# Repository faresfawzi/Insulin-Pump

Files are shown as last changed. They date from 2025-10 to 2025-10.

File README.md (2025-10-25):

# Open Source AI-Enhanced 3D-Printed Insulin Pump
## Abstract
This research aims to develop functional 3D printed low-cost wearable insulin pumps for precise and personalized dosing for type 1 diabetes mellitus (T1DM) patients. The system utilizes artificial intelligence (AI) insulin to predict personalized bolus insulin dosages and send the dosing configuration wirelessly to an in-house developed IoT-reconfigurable pumping system to deliver the specified dosage to the patient. Historical patients’ data are fed to a cloud-based machine learning model to predict the personalized amount of bolus insulin based on the patient’s blood glucose levels, the amount of carbohydrates consumed, and physical activity. The system delivers U100 insulin bolus dosage at a flow rate of 750μl/min against an estimated 0.764 kPa backpressure produced by the patient’s subcutaneous tissue, which is 6 to 8 times faster than current insulin pumping systems. In addition to the system’s AI-enhancement, IoT connectivity, small footprint, and low power consumption, the system’s cost is predicted at under $35, making it an excellent candidate to fill a market gap and act as a fully autonomous artificial pancreas that improves the quality of life of T1DM patients.

## Citation

If you build on this project, please cite this paper.

```
@inproceedings{fawzi2023open,
  title={Open Source AI-Enhanced 3D-Printed Insulin Pump},
  author={Fawzi, Fares and Sedky, Mostafa and Abohammar, Youssef and Sharara, Hossam and Serry, Mohamed},
  booktitle={2023 IEEE Applied Sensing Conference (APSCON)},
  pages={1--4},
  year={2023},
  organization={IEEE}
}
```

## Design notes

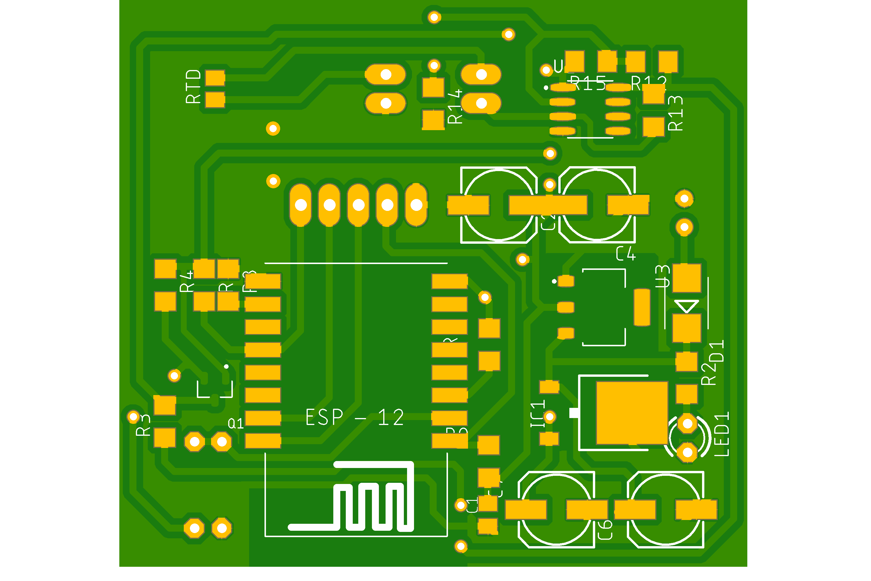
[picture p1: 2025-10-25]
RTD/RTD Sesnor.png

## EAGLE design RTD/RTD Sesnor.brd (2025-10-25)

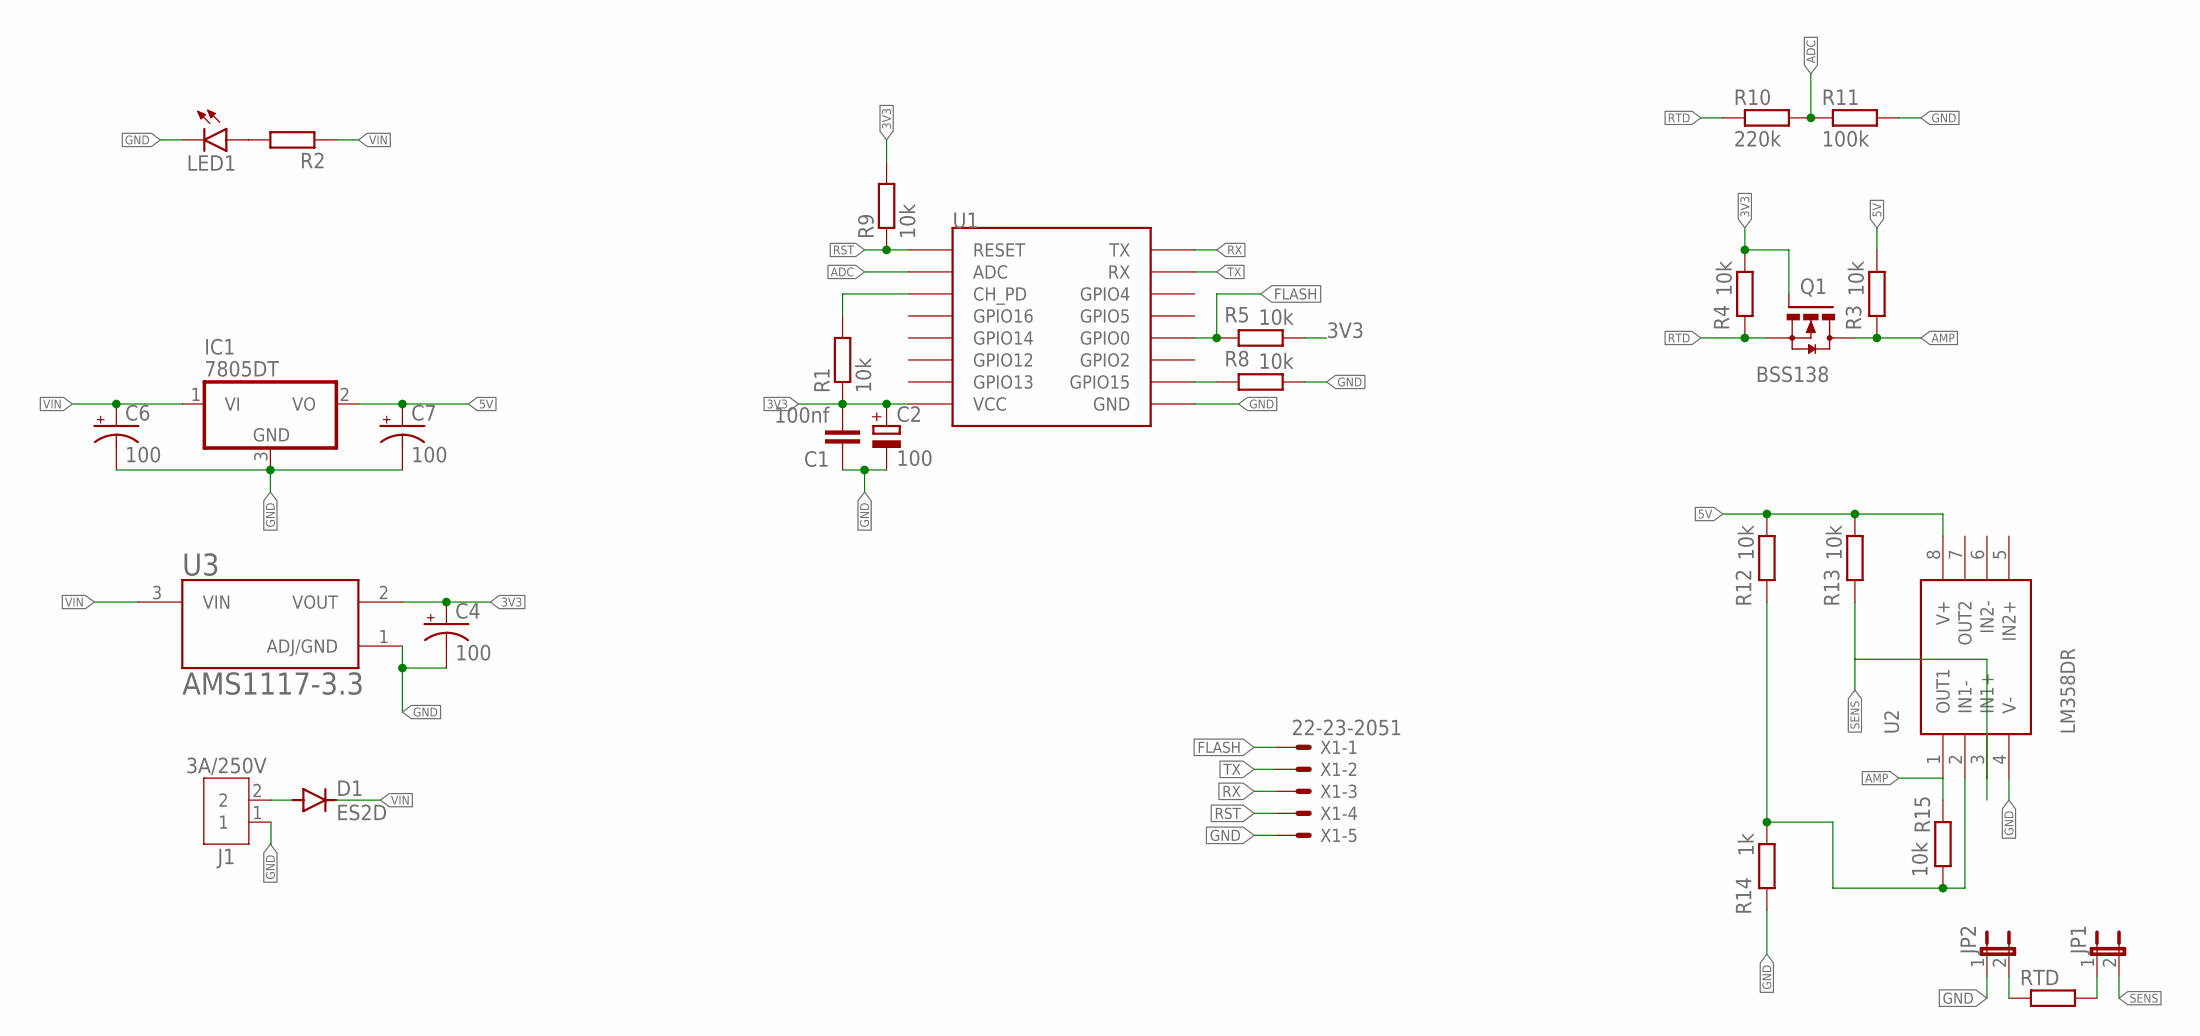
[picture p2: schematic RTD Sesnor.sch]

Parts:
C1: 100nf; C0805K
C2, C4, C6, C7: 100; 153CLV-0605
D1: ES2D; SMB
IC1: 7805DT; TO252
J1: 3A/250V; B2B-XH-A
JP1, JP2: JP1E; JP1
LED1: LED3MM
Q1: BSS138; SOT23-3
R1, R3, R4, R5, R8, R9, R12, R13, R15: 10k; R1206
R2: R-EU_R1206; R1206
R10: 220k; 0204/7
R11: 100k; 0204/7
R14: 1k; R1206
RTD: R-EU_M0805; M0805
U1: ESP12SMD; ESP12-SMD
U2: LM358DR
U3: AMS1117-3.3; SOT229P700X180-4N
X1: 22-23-2051

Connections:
3V3: C1.2, C2.+, C4.+, Q1.1 (G), R1.1, R4.1, R5.1, R9.2, U1.VCC, U3.2 (VOUT)
5V: C7.+, IC1.2 (VO), R3.1, R12.1, R13.1, U2.8 (V+)
ADC: R10.2, R11.1, U1.ADC
AMP: Q1.3 (D), R3.2, R15.2, U2.1 (OUT1)
FLASH: R5.2, U1.GPIO0, X1.1
GND: C1.1, C2.-, C4.-, C6.-, C7.-, IC1.3 (GND), J1.1, JP2.1, LED1.K (C), R8.1, R11.2, R14.2, U1.GND, U2.4 (V-), U3.1 (ADJ/GND), X1.5
unnamed: R1.2, U1.CH_PD
unnamed: LED1.A, R2.2
unnamed: JP2.2, RTD.1
unnamed: JP1.1, RTD.2
unnamed: R8.2, U1.GPIO15
unnamed: D1.A, J1.2
unnamed: R12.2, R14.1, R15.1, U2.2 (IN1-)
RST: R9.1, U1.RESET, X1.4
RTD: Q1.2 (S), R4.2, R10.1
RX: U1.TXD0 (TX), X1.3
SENS: JP1.2, R13.2, U2.3 (IN1+)
TX: U1.RXD0 (RX), X1.2
VIN: C6.+, D1.C, IC1.1 (VI), R2.1, U3.3 (VIN)

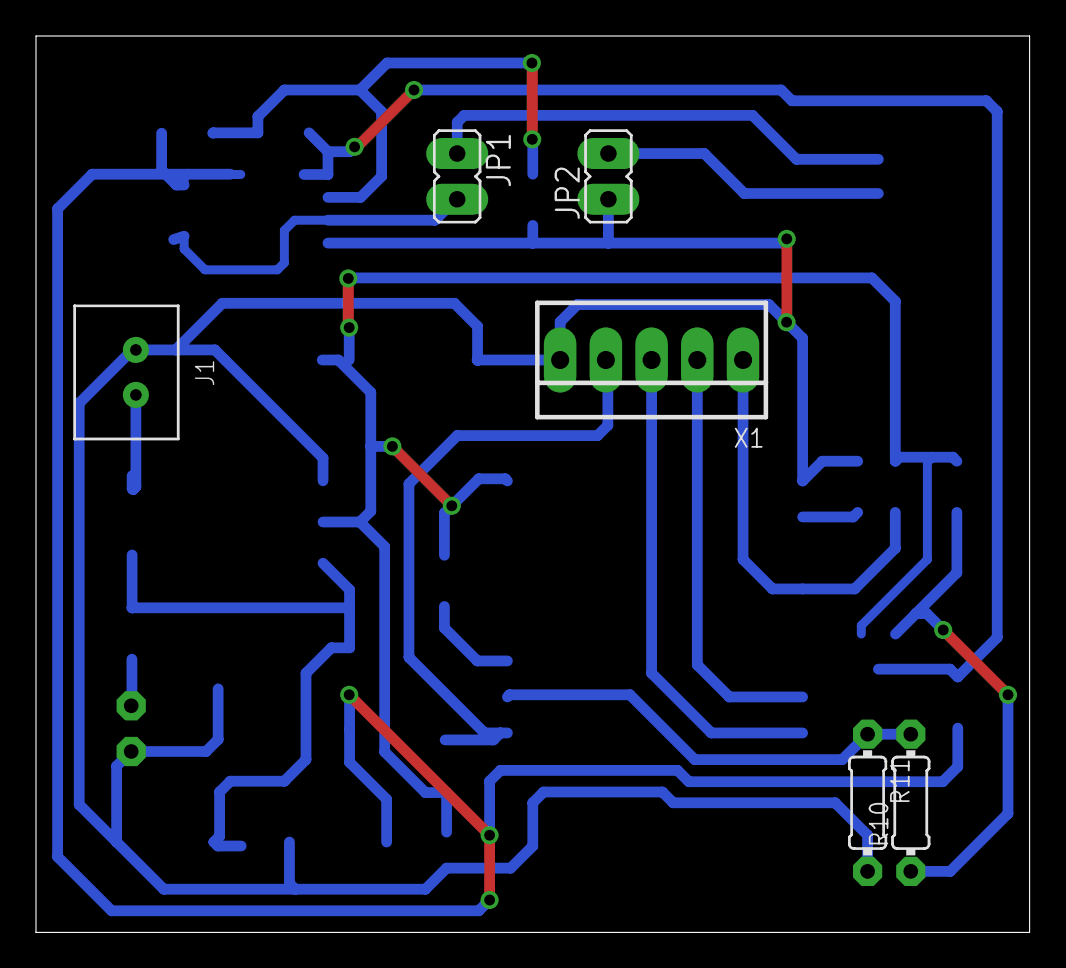
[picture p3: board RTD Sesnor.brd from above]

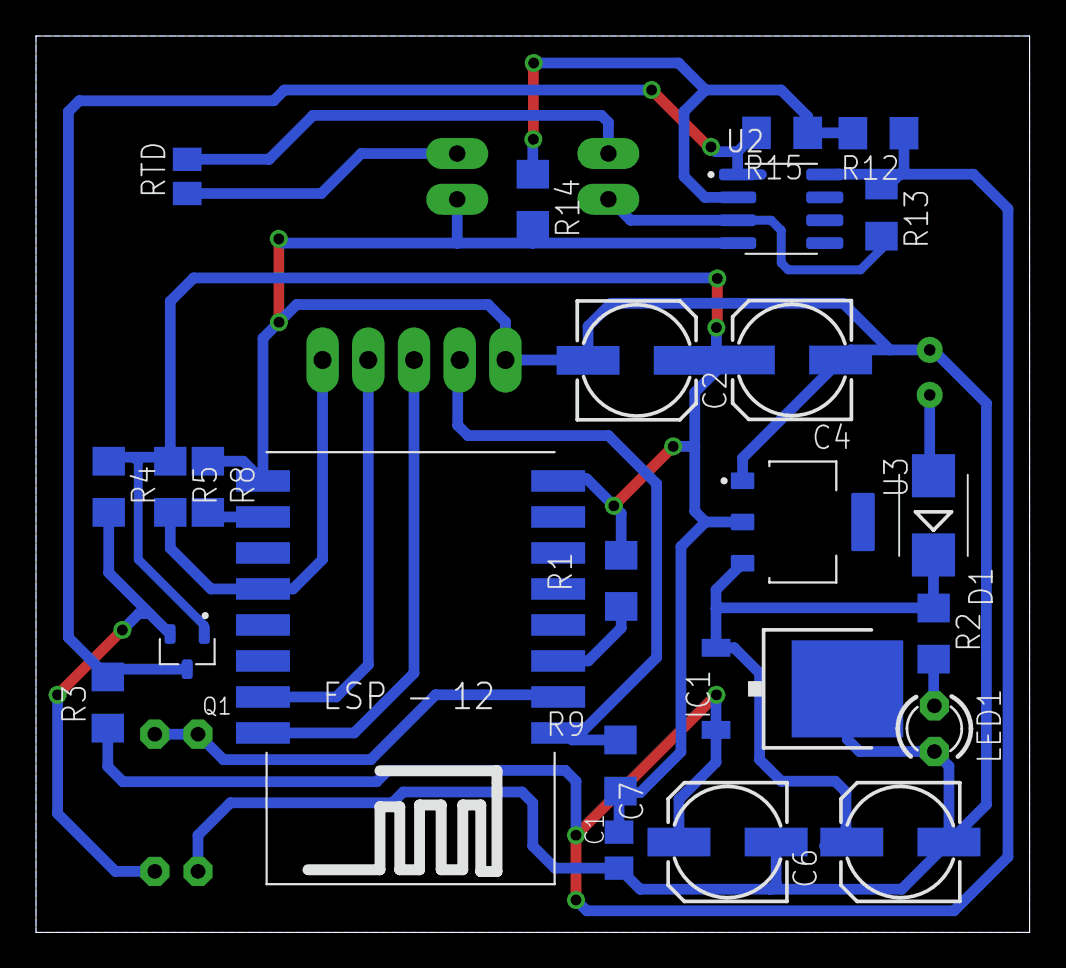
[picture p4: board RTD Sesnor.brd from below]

Board: 2 copper layers, 55.2 x 49.8 mm, 30 parts (24 on the bottom side), 19 nets.

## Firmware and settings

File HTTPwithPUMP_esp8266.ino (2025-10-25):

float Sens=100; //mV/mT, this is 12.5 for A4 version
float Stc=0.0012; //%/Celcius
float Ta=25;
float Vq=5/2; //half of sensor input voltage
//float B1;
float B2;
float Distime[] = {};
float Vout1;
float Vout2;
//int HallPin1=A0;
//int HallPin2=A2; 
float Bact;

//******************CHANGE THIS**************************
float frequency=10;//Hz
const float flowrate=6.558222222; // ml/min 
//*****************************************************

const float dutyCycle=0.4;
float offTime=1000.0/frequency*(1-dutyCycle);
float onTime=1000.0/frequency*dutyCycle;

//float offTime=33;
//float onTime=12.5;

float power;
float time_on;
float time_off;
float total_time;
int  Writestatus = 200;
#define HallPin A4

#include <ESP8266WiFi.h>
#include <ESP8266HTTPClient.h>
#include <WiFiClient.h>

//#include <WiFi.h>
//#include <HTTPClient.h>
//#include <HttpClient.h>

#include <ArduinoJson.h>
const char* ssid = "Fares1";
const char* password = "mariam98";

//#define STASSID "Fares1"
//#define STAPSK  "mariam98"

//Your Domain name with URL path or IP address with path
String serverName = "https://t1ly8glf7c.execute-api.us-east-1.amazonaws.com/prod-get/data"; //aws API Gateway url, Need htps:// pre-fix for ESP32 sketch
const char* API_KEY = "uzpjEVoFFz3TZQkzGS8GxRHjHAYGxN181OwDplr4"; //Your AWS API-Key

// the following variables are unsigned longs because the time, measured in
// milliseconds, will quickly become a bigger number than can be stored in an int.
unsigned long lastTime = 0;
// Timer set to 10 minutes (600000)
//unsigned long timerDelay = 600000;
// Set timer to 5 seconds (5000)
unsigned long timerDelay = 5000;
unsigned long Uptime;
String json_post(float carbs);
double carbs_get=0;
double carbs_old=1000;
void setup() {
  Serial.begin(115200); 

  WiFi.begin(ssid, password);
  //WiFi.begin(STASSID, STAPSK);
  Serial.println("Connecting");
  while(WiFi.status() != WL_CONNECTED) {
    delay(500);
    Serial.print(".");
  }
  Serial.println("");
  Serial.print("Connected to WiFi network with IP Address: ");
  Serial.println(WiFi.localIP());
 
  Serial.println("Timer set to 5 seconds (timerDelay variable), it will take 5 seconds before publishing the first reading.");

  pinMode(19,OUTPUT);
  pinMode(21,OUTPUT);
  pinMode(18,OUTPUT);
  pinMode(2,OUTPUT);
  pinMode(4,OUTPUT);
  digitalWrite(19,LOW);   
  digitalWrite(21,LOW);
  digitalWrite(2,LOW);
  digitalWrite(4,LOW); 

   
  
}
String body;
bool flag=true;
void loop() {

  
  //Send an HTTP POST request every 10 minutes
  if ((millis() - lastTime) > timerDelay) {
    //Check WiFi connection status
    if(WiFi.status()== WL_CONNECTED){
     // Pump();
     carbs_get=json_get();
     while (carbs_get!= carbs_old){
     while (flag==true){
          
          Serial.println(carbs_get);
          carbs_old=carbs_get;

          String pred=json_post(carbs_get);

          Serial.println("Pred: ");
          Serial.println(pred);
          float pred_float=pred.toFloat();
      
          
      
  
      long   starttime = millis();
      long    endtime = starttime;
          while ((endtime - starttime) <=(((pred_float/100)*60/flowrate)*1000)) // do this loop for up to 1000mS
         // while ( (endtime - starttime) <= (((10.0/100)*60/flowrate)*1000)+2000) // do this loop for up to 1000mS
            {
                Serial.println("Pumping");       
                Pump();
                endtime = millis();
                Serial.println(endtime - starttime);
            }
          flag=false;

         

         }

      }

    }



    
}
}

double json_get(){
double carbs;
   // WiFiClient client;
    WiFiClientSecure client;
    client.setInsecure();
    HTTPClient http;
       //HTTPClient http;
      // Your Domain name with URL path or IP address with path
      String serverPath = "https://t1ly8glf7c.execute-api.us-east-1.amazonaws.com/prod-get/data";
      http.begin(client, serverPath.c_str());
      
      // Send HTTP GET request
      int httpResponseCode = http.GET();
      
      if (httpResponseCode>0) {
        Serial.print("HTTP Response code: ");
        Serial.println(httpResponseCode);
        String payload = http.getString();
        Serial.println(payload);
        
        //StaticJsonBuffer<200> jsonBuffer;

       //JsonObject& root = jsonBuffer.parseObject(httpResponseCode);
       //const double carbs = payload["Item"]["carbs"];
        DynamicJsonDocument doc(2048);
        DeserializationError err = deserializeJson(doc,payload);

        if (err){
          Serial.print("Error: ");
          Serial.println(err.c_str());
     }

       carbs=doc["Item"]["carbs"] ;

      }
      else {
        Serial.print("Error code: ");
        Serial.println(httpResponseCode);
      }
      // Free resources
      http.end();

      return carbs;
}


String json_post(float carbs){

    // HTTPClient client;
    WiFiClientSecure client;
    client.setInsecure(); 
    HTTPClient http;
     
     http.begin(client,"https://k86fih2os8.execute-api.us-east-1.amazonaws.com/default/xgboostcontainer1");
     http.addHeader("Content-Type","application/json");

     DynamicJsonDocument doc(2048);

     JsonObject object=doc.to<JsonObject>();
     object["BG"]=100;
     object["carbs"]=carbs;
     object["bas"]=0.01393333;
     
     char jsonOutput[700];
     
     serializeJson(doc,jsonOutput);

     int httpCode=http.POST(String(jsonOutput));

     if(httpCode>0){
      
      String payload=http.getString();
      //Serial.println("\nStatuscode: " + String(httpCode));
      //Serial.println(payload);
      http.end();

      DynamicJsonDocument doc2(2048);
      DeserializationError err = deserializeJson(doc2,payload);
      if (err){
          Serial.print("Error: ");
          Serial.println(err.c_str());
     }

     
     body=doc2["body"].as<String>();
     
     //Serial.println(body);
      
      }
    int firstBracket = body.indexOf('[');
    int lastBracket = body.indexOf(']');
    String pred=body.substring(firstBracket+1, lastBracket);  


    return pred;
 
  

}




void Pump()
{


  digitalWrite(19,LOW);
  digitalWrite(21,HIGH);
//  Serial.println("CLOSED");
//  Vout1=(analogRead(HallPin1)*5.0)/1023.0;
//  B1=(Vout1-Vq)/(Sens*(1+Stc*(Ta-25)));

    
  digitalWrite(2,LOW); 
  digitalWrite(4,HIGH);
//  Vout2=(analogRead(HallPin2)*5.0)/1023.0;
//  B2=(Vout2-Vq)/(Sens*(1+Stc*(Ta-25)));
  //Serial.println(Vout1);
//  Serial.print(',');
//  Serial.println(Vout2);
  

  delay(onTime);

  digitalWrite(2,LOW); 
  digitalWrite(4,LOW);
  //Vout1=(analogRead(HallPin1)*5.0)/1023.0;
//  B1=(Vout1-Vq)/(Sens*(1+Stc*(Ta-25)));


  digitalWrite(19,HIGH);
  digitalWrite(21,LOW);
//  Serial.println("NEUTRAL");
//  Vout2=(analogRead(HallPin2)*5.0)/1023.0;
//  B2=(Vout2-Vq)/(Sens*(1+Stc*(Ta-25)));
 // Serial.println(Vout1);
//  Serial.print(',');
//  Serial.println(Vout2);
  

  delay(offTime/10);

  
  digitalWrite(2,LOW); 
  digitalWrite(4,LOW);
//  Vout1=(analogRead(HallPin1)*5.0)/1023.0;
  Bact=(Vout1-Vq)/(Sens*(1+Stc*(Ta-25)));


  digitalWrite(19,LOW);
  digitalWrite(21,LOW);
//  Serial.println("NEUTRAL");
//  Vout2=(analogRead(HallPin2)*5.0)/1023.0;
//  B2=(Vout2-Vq)/(Sens*(1+Stc*(Ta-25)));
 // Serial.println(Vout1);
//  Serial.print(',');
//  Serial.println(Vout2);
  
  

  delay((9*offTime)/10);
}

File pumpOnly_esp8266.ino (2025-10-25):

float Sens=100; //mV/mT, this is 12.5 for A4 version
float Stc=0.0012; //%/Celcius
float Ta=25;
float Vq=5/2; //half of sensor input voltage
//float B1;
float B2;
float Distime[] = {};
float Vout1;
float Vout2;
int HallPin1=A0;
//int HallPin2=A2; 
float Bact;

float frequency=9;//Hz
const float dutyCycle=0.4;


float offTime=1000.0/frequency*(1-dutyCycle);
float onTime=1000.0/frequency*dutyCycle;

//float offTime=33;
//float onTime=12.5;

float power;
float time_on;
float time_off;
float total_time;
int  Writestatus = 200;
#define HallPin A4



void setup() {
  // put your setup code here, to run once:
  Serial.begin(115200); 
 // pinMode(HallPin,INPUT);
  //pinMode (en, OUTPUT);
  pinMode(7,OUTPUT);
  pinMode(8,OUTPUT);
  pinMode(6,OUTPUT);
  pinMode(12,OUTPUT);
  pinMode(2,OUTPUT);
  digitalWrite(7,LOW);
  digitalWrite(8,LOW);
  digitalWrite(12,LOW);
  digitalWrite(2,LOW);  
}

void loop() {
  // put your main code here, to run repeatedly:

       Pump();

}


void Pump()
{


  digitalWrite(7,LOW);
  digitalWrite(8,HIGH);
//  Serial.println("CLOSED");
  Vout1=(analogRead(HallPin1)*5.0)/1023.0;
//  B1=(Vout1-Vq)/(Sens*(1+Stc*(Ta-25)));

    
  digitalWrite(2,LOW); 
  digitalWrite(12,HIGH);
 // Vout2=(analogRead(HallPin2)*5.0)/1023.0;
//  B2=(Vout2-Vq)/(Sens*(1+Stc*(Ta-25)));
  Serial.println("HERE");
//  Serial.print(',');
//  Serial.println(Vout2);
  

  delay(onTime);
  Serial.println("pumpoff");
  digitalWrite(12,LOW); 
  digitalWrite(2,LOW);
  Vout1=(analogRead(HallPin1)*5.0)/1023.0;
//  B1=(Vout1-Vq)/(Sens*(1+Stc*(Ta-25)));


  digitalWrite(7,HIGH);
  digitalWrite(8,LOW);
//  Serial.println("NEUTRAL");
 // Vout2=(analogRead(HallPin2)*5.0)/1023.0;
//  B2=(Vout2-Vq)/(Sens*(1+Stc*(Ta-25)));
  Serial.println(Vout1);
//  Serial.print(',');
//  Serial.println(Vout2);
  

  delay(offTime/10);

  
  digitalWrite(12,LOW); 
  digitalWrite(2,LOW);
  Vout1=(analogRead(HallPin1)*5.0)/1023.0;
  Bact=(Vout1-Vq)/(Sens*(1+Stc*(Ta-25)));


  digitalWrite(7,LOW);
  digitalWrite(8,LOW);
//  Serial.println("NEUTRAL");
//  Vout2=(analogRead(HallPin2)*5.0)/1023.0;
//  B2=(Vout2-Vq)/(Sens*(1+Stc*(Ta-25)));
  Serial.println(Vout1);
//  Serial.print(',');
//  Serial.println(Vout2);
  
  

  //delay((9*offTime)/10);
  delay(20000);
}

/*void HallSensor()
{
  
  float vsum = 0;
  float bsum = 0;
  float a[]={};
  float asum;
  //Serial.print("Inside of function\n");
  for (int i = 0; i <= 50; i++)
  {
    a[i]=analogRead(HallPin);
    asum=asum+a[i];
    Vout[i]=(a[i]*5.0)/1023.0;
    vsum = vsum + Vout[i];
    B[i]=(Vout[i]-Vq)*1000/(Sens*(1+Stc*(Ta-25)));
    bsum = bsum + B[i];
 }
 //Serial.println(asum/50);
 Serial.println(vsum/50);
 Serial.println(bsum/50); 
     
}*/
